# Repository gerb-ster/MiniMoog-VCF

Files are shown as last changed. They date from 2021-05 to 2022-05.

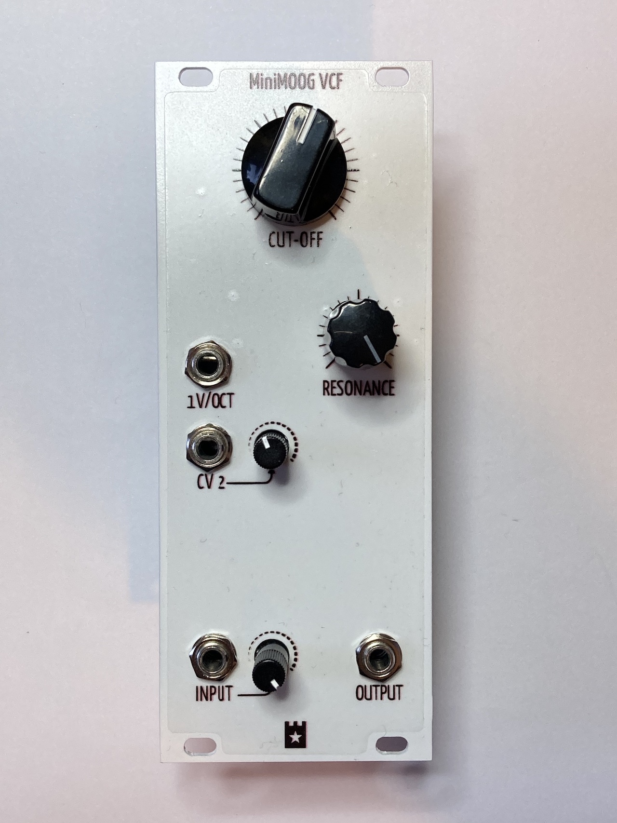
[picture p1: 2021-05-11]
images/IMG_3972.jpeg

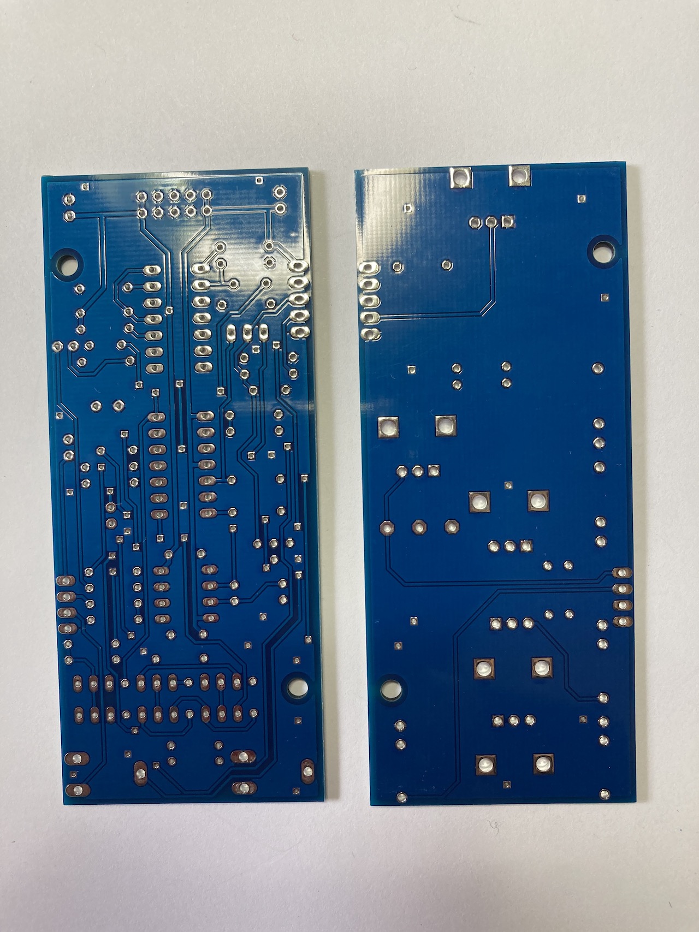
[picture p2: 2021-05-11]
images/IMG_3997.jpeg

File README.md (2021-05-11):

# YUSynth MiniMoog VCF

No system is complete without some good VCF’s. And one excellent source for some good VCF is designs is, offcourse, the website of Yven Usson, also known as YuSynth. And this VCF is no exception. It’s a clone of the famous VCF found in the MiniMoog. I’ve made an eurorack version.

## Status: Finished

- done: first schematic & board design
- done: breadboard and test
- done: design frontpanel
- done: order PCB and build prototype

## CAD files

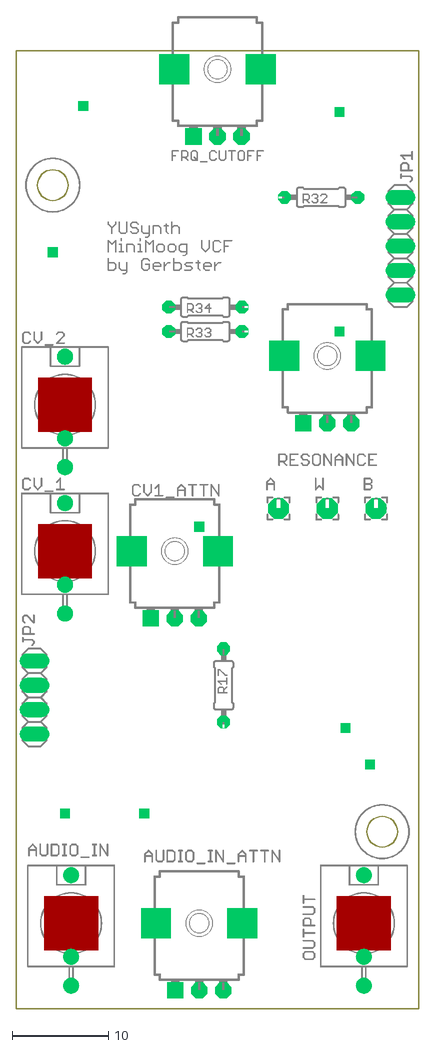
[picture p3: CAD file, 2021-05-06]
faceplates/MoogFilter.dxf
41.9 x 103.3

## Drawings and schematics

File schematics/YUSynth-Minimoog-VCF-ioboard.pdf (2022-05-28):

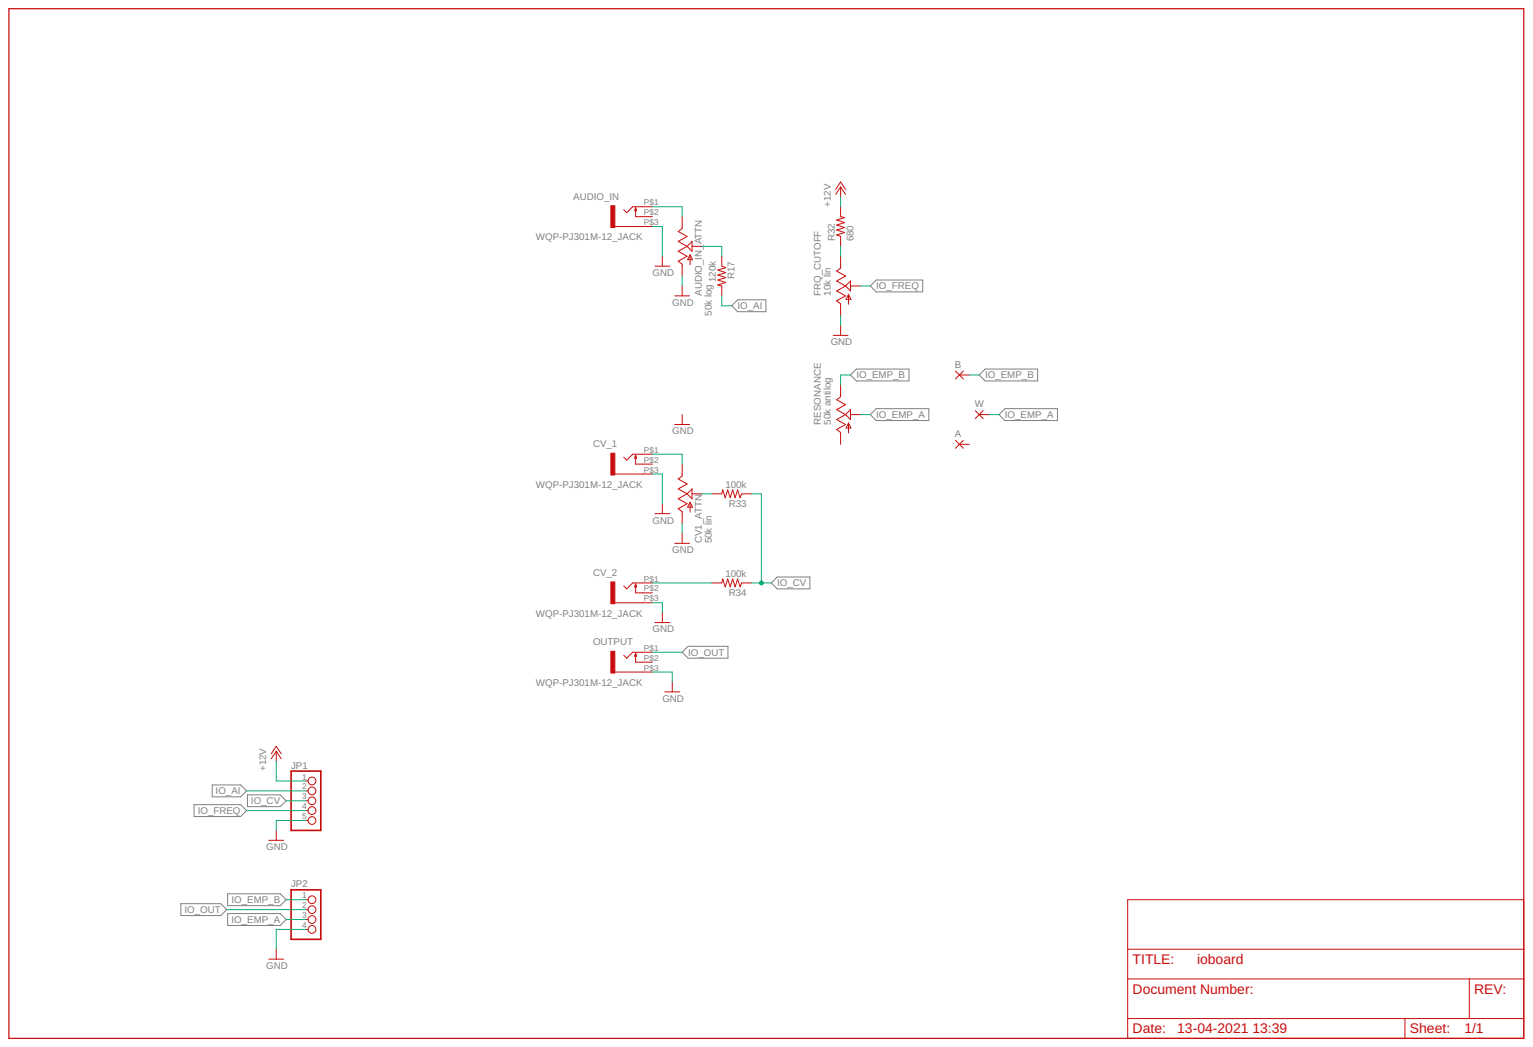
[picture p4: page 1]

120k GND GND +12V GND680 WQP-PJ301M-12_JACK WQP-PJ301M-12_JACK WQP-PJ301M-12_JACK WQP-PJ301M-12_JACK 10k lin 50k antilog 50k lin GND GND GNDGND +12V GND 50k log 100k 100k GND GND R17 12345 JP1 R32P$3 P$1 P$2 AUDIO_IN P$3 P$1 P$2 CV_1 P$3 P$1 P$2 CV_2 P$3 P$1 P$2 OUTPUT FRQ_CUTOFF RESONANCE CV1_ATTN AUDIO_IN_ATTN R33 R34 1234 JP2 B W A IO_AI IO_AI IO_CV IO_CV IO_OUT IO_OUT IO_EMP_B IO_EMP_B IO_EMP_B IO_EMP_A IO_EMP_A IO_EMP_A IO_FREQ IO_FREQ Date: Sheet: REV: TITLE: Document Number: 13-04-2021 13:39 1/1 ioboard

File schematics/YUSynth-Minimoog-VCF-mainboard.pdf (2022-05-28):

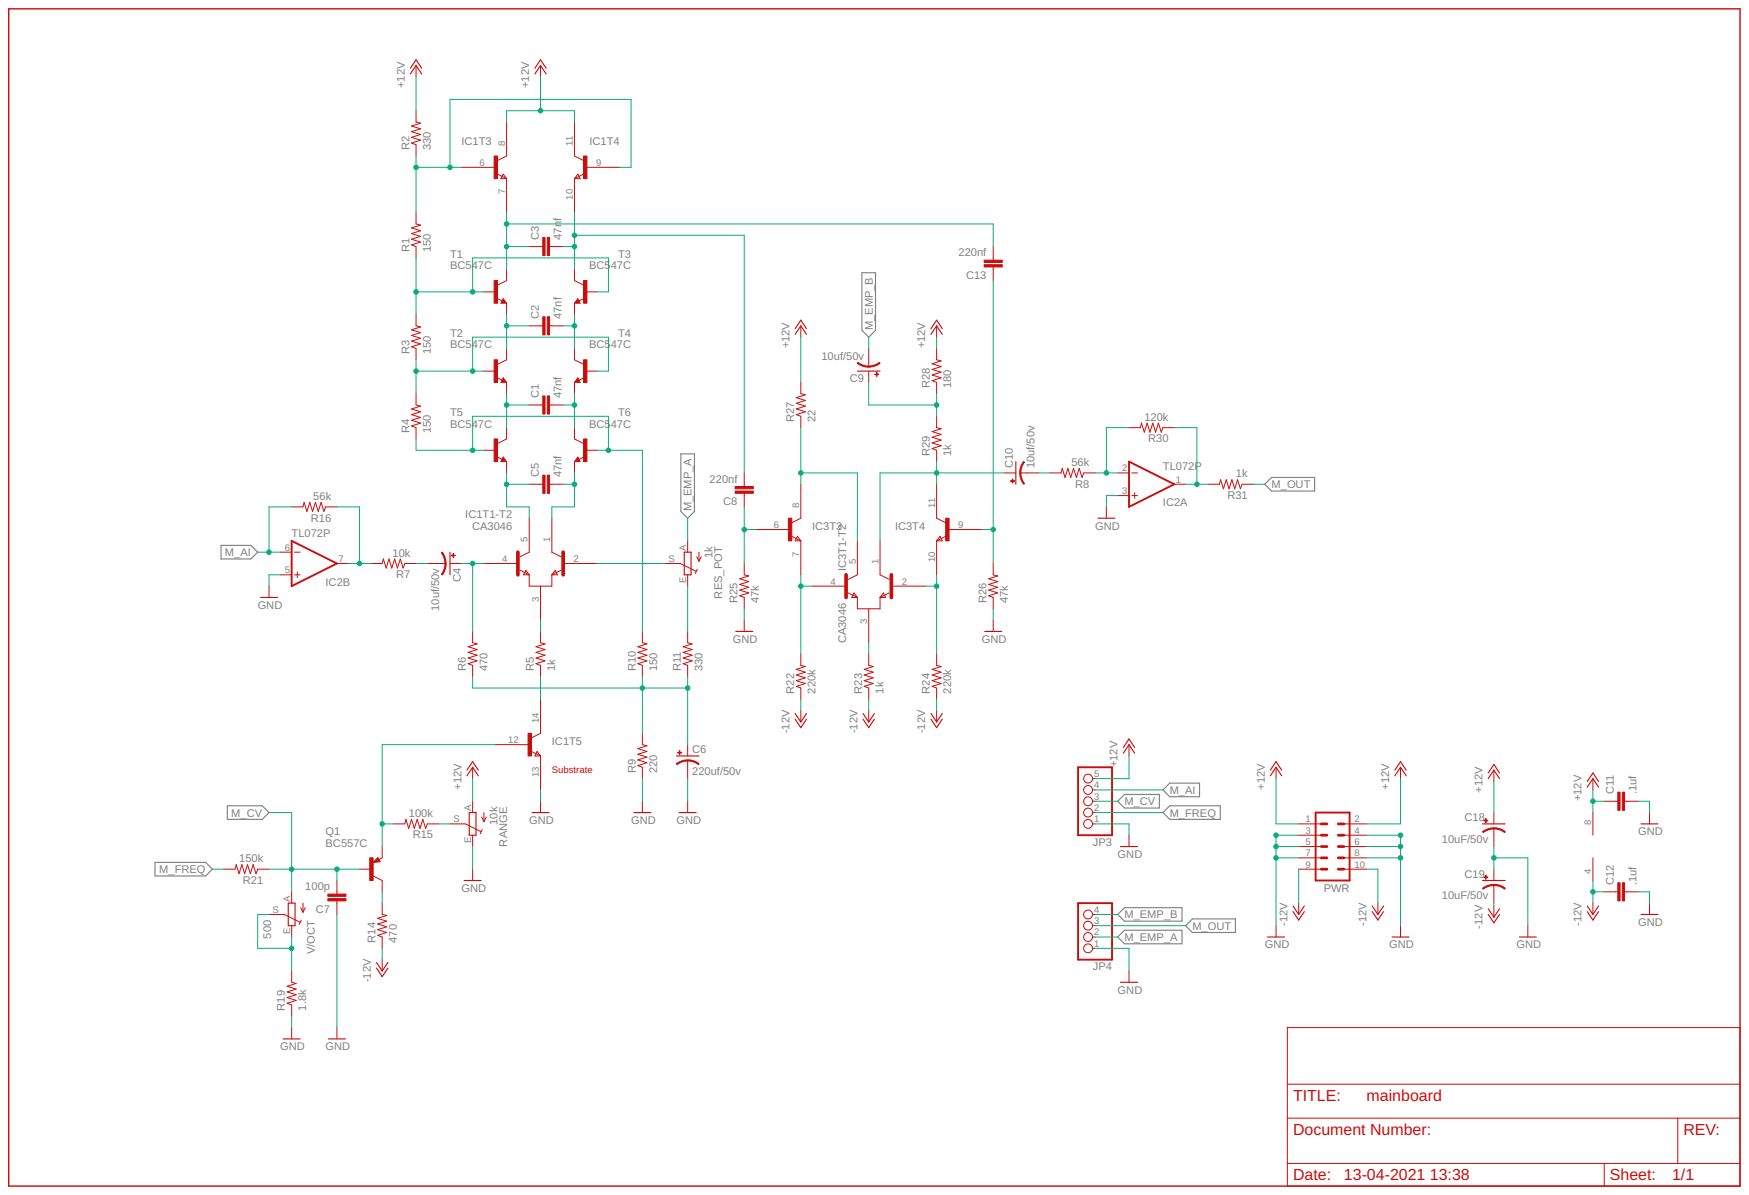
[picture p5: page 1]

Document Number: | REV:

Date: 13-04-2021 13:38 | Sheet: 1/1

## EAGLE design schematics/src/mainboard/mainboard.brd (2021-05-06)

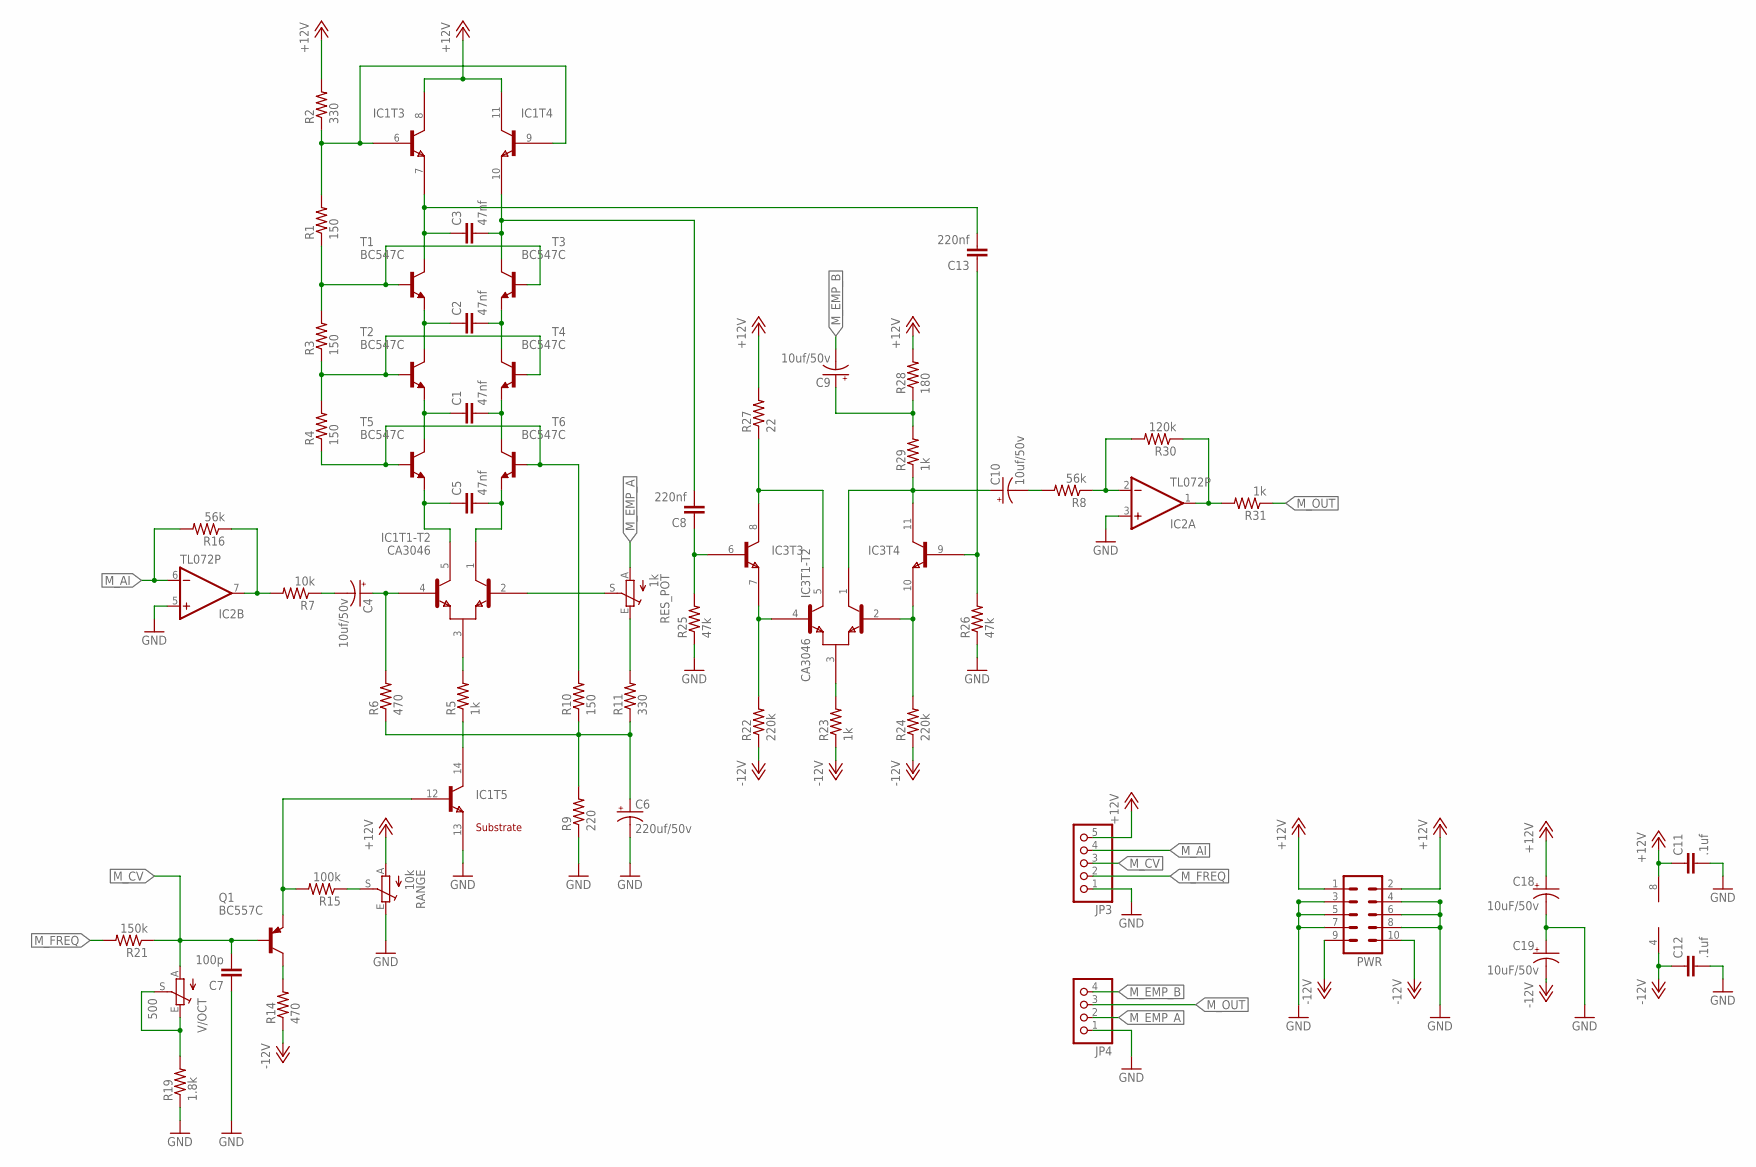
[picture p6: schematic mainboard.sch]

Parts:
C1, C2, C3, C5: 47nf; C050-024X044
C4, C9, C10: 10uf/50v; E2,5-5
C6: 220uf/50v; E3,5-10
C7: 100p; C050-024X044
C8, C13: 220nf; C050-024X044
C11, C12: .1uf; C050-024X044
C18, C19: 10uF/50v; E2,5-6
IC1, IC3: CA3046; DIL14
IC2: TL072P; DIL08
JP3: PINHD-1X5; 1X05
JP4: PINHD-1X4; 1X04
PWR: ML10
Q1: BC557C; TO92-EBC
R1, R3, R4, R10: 150; 0204/7
R2, R11: 330; 0204/7
R5, R23, R29, R31: 1k; 0204/7
R6, R14: 470; 0204/7
R7: 10k; 0204/7
R8, R16: 56k; 0204/7
R9: 220; 0204/7
R15: 100k; 0204/7
R19: 1.8k; 0204/7
R21: 150k; 0204/7
R22, R24: 220k; 0204/7
R25, R26: 47k; 0204/7
R27: 22; 0204/7
R28: 180; 0204/7
R30: 120k; 0204/7
RANGE: 10k; CA9V
RES_POT: 1k; CA9V
T1, T2, T3, T4, T5, T6: BC547C; TO92-CBE
V/OCT: 500; S64YW

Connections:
+12V: C11.1, C18.+, IC1.8 (C), IC1.11 (C), IC2.8 (V+), JP3.5, PWR.1, PWR.2, R2.2, R27.2, R28.2, RANGE.A
-12V: C12.1, C19.-, IC2.4 (V-), PWR.9, PWR.10, R14.1, R22.1, R23.1, R24.1
GND: C6.-, C7.1, C11.2, C12.2, C18.-, C19.+, IC1.13 (E), IC2.3 (+IN), IC2.5 (+IN), JP3.1, JP4.1, PWR.3, PWR.4, PWR.5, PWR.6, PWR.7, PWR.8, R9.1, R19.1, R25.1, R26.1, RANGE.E
M_AI: IC2.6 (-IN), JP3.4, R16.2
M_CV: C7.2, JP3.3, Q1.B, R21.1, V/OCT.A
M_EMP_A: JP4.2, RES_POT.A
M_EMP_B: C9.-, JP4.4
M_FREQ: JP3.2, R21.2
M_OUT: JP4.3, R31.1
unnamed: C5.1, IC1.5 (C2), T5.E
unnamed: IC1.6 (B), IC1.9 (B), R1.2, R2.1
unnamed: C3.1, C13.2, IC1.7 (E), T1.C
unnamed: C3.2, C8.2, IC1.10 (E), T3.C
unnamed: C2.1, T1.E, T2.C
unnamed: C2.2, T3.E, T4.C
unnamed: C1.1, T2.E, T5.C
unnamed: C1.2, T4.E, T6.C
unnamed: R1.1, R3.2, T1.B, T3.B
unnamed: R3.1, R4.2, T2.B, T4.B
unnamed: R4.1, R10.2, T5.B, T6.B
unnamed: C5.2, IC1.1 (C1), T6.E
unnamed: IC1.3 (E), R5.2
unnamed: IC1.14 (C), R5.1
unnamed: C4.+, IC1.4 (B2), R6.2
unnamed: C4.-, R7.1
unnamed: C6.+, R6.1, R9.2, R10.1, R11.1
unnamed: IC2.7 (OUT), R7.2, R16.1
unnamed: R19.2, V/OCT.E, V/OCT.S
unnamed: IC1.12 (B), Q1.E, R15.2
unnamed: IC1.2 (B1), RES_POT.S
unnamed: R11.2, RES_POT.E
unnamed: C13.1, IC3.9 (B), R26.2
unnamed: Q1.C, R14.2
unnamed: R15.1, RANGE.S
unnamed: C10.-, R8.2
unnamed: IC3.4 (B2), IC3.7 (E), R22.2
unnamed: IC3.3 (E), R23.2
unnamed: IC3.2 (B1), IC3.10 (E), R24.2
unnamed: IC3.5 (C2), IC3.8 (C), R27.1
unnamed: C10.+, IC3.1 (C1), IC3.11 (C), R29.1
unnamed: C9.+, R28.1, R29.2
unnamed: IC2.1 (OUT), R30.1, R31.2
unnamed: C8.1, IC3.6 (B), R25.2
unnamed: IC2.2 (-IN), R8.1, R30.2

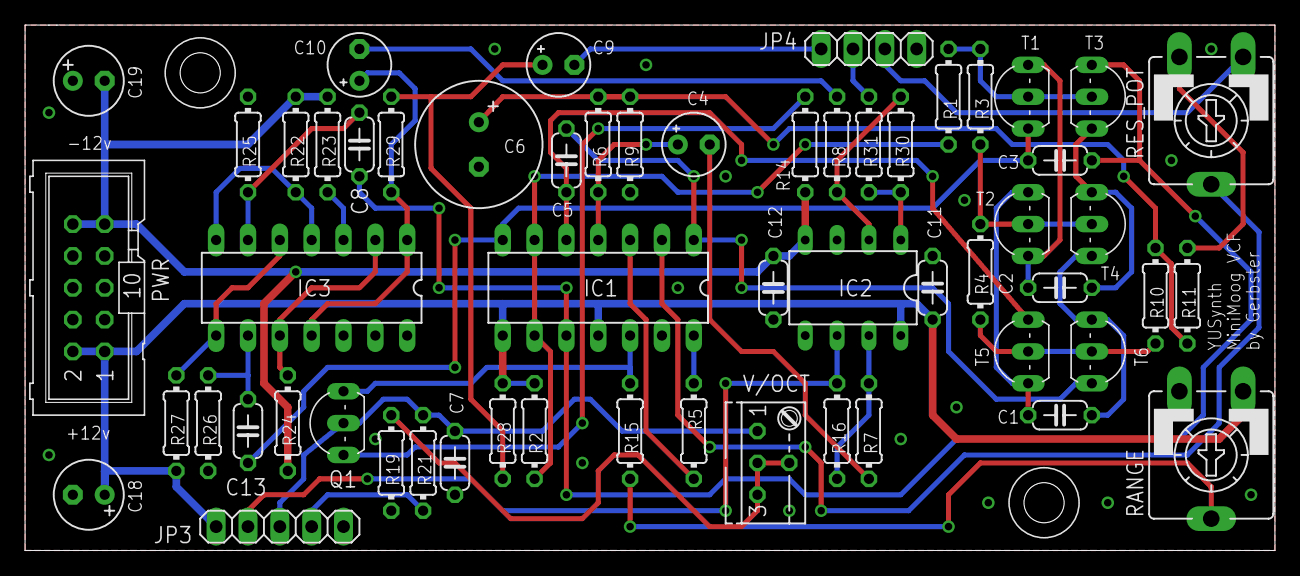
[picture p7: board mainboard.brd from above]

Board: 2 copper layers, 99.7 x 41.9 mm, 57 parts (0 on the bottom side), 44 nets.

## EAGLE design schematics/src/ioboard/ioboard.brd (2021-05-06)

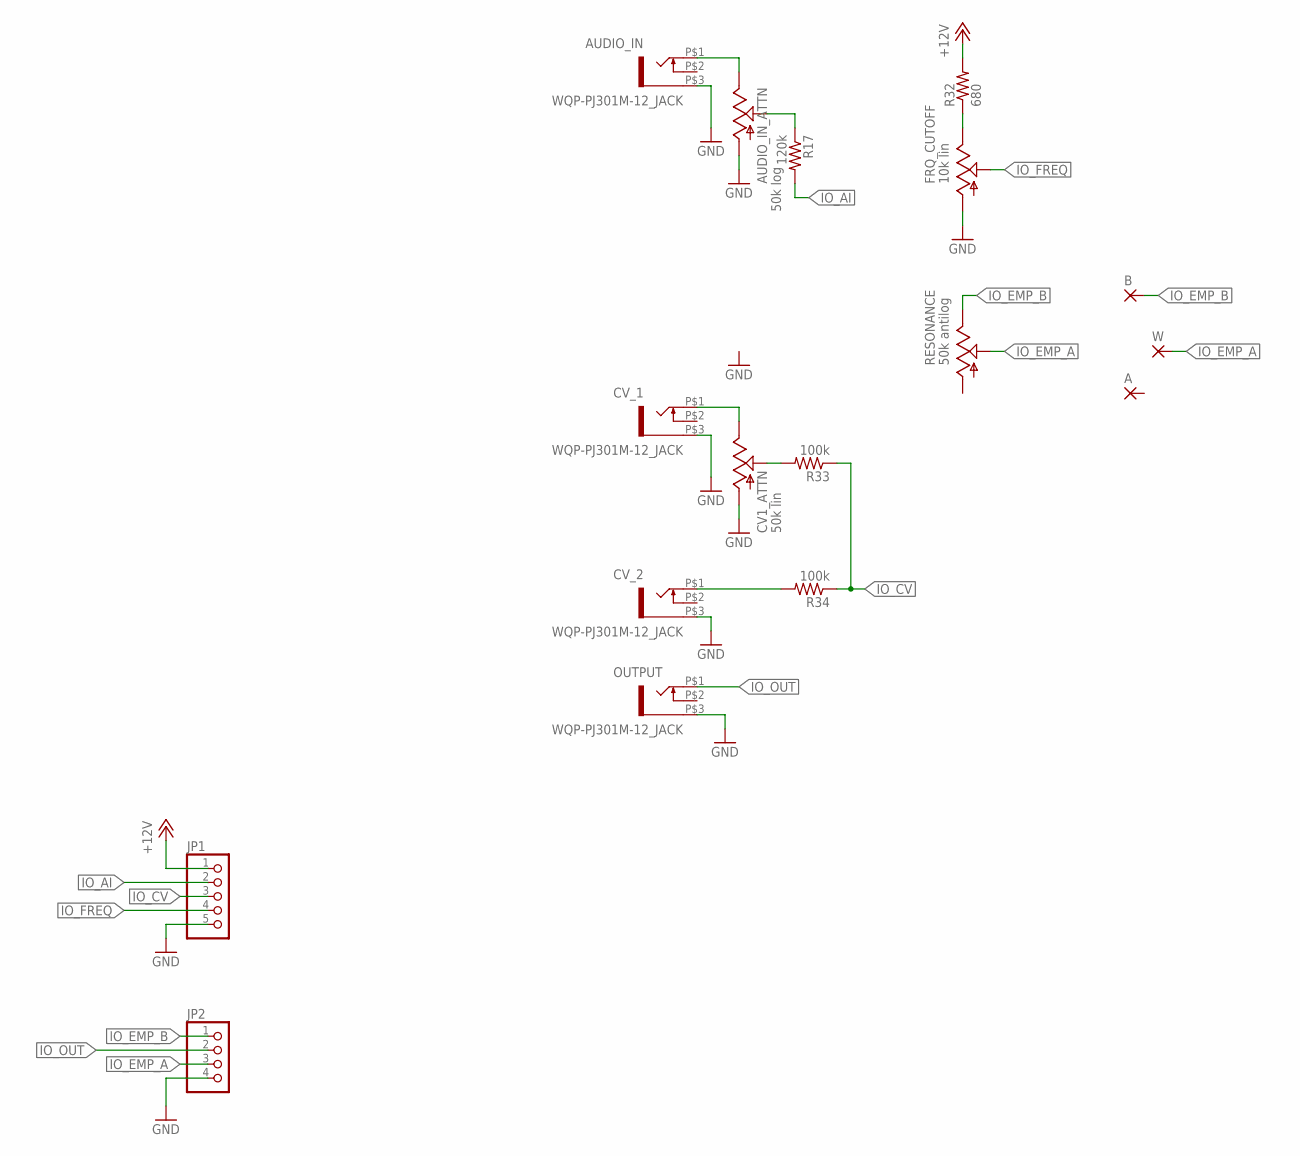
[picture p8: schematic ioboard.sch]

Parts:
A: 2,15/1,0
AUDIO_IN: WQP-PJ301M-12_JACK
AUDIO_IN_ATTN: 50k log; EVUF
B: 2,15/1,0
CV1_ATTN: 50k lin; EVUF
CV_1, CV_2: WQP-PJ301M-12_JACK
FRQ_CUTOFF: 10k lin; EVUF
JP1: PINHD-1X5; 1X05
JP2: PINHD-1X4; 1X04
OUTPUT: WQP-PJ301M-12_JACK
R17: 120k; 0204/7
R32: 680; 0204/7
R33, R34: 100k; 0204/7
RESONANCE: 50k antilog; EVUF
W: 2,15/1,0

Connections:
+12V: JP1.1, R32.2
GND: AUDIO_IN.P$3 (1), AUDIO_IN_ATTN.1 (A), CV1_ATTN.1 (A), CV_1.P$3 (1), CV_2.P$3 (1), FRQ_CUTOFF.1 (A), JP1.5, JP2.4, OUTPUT.P$3 (1)
IO_AI: JP1.2, R17.2
IO_AI_1: AUDIO_IN_ATTN.2 (S), R17.1
IO_CV: JP1.3, R33.1, R34.1
IO_EMP_A: JP2.3, RESONANCE.2 (S), W.1
IO_EMP_B: B.1, JP2.1, RESONANCE.3 (E)
IO_FREQ: FRQ_CUTOFF.2 (S), JP1.4
IO_OUT: JP2.2, OUTPUT.P$1 (2)
unnamed: FRQ_CUTOFF.3 (E), R32.1
unnamed: CV1_ATTN.3 (E), CV_1.P$1 (2)
unnamed: CV1_ATTN.2 (S), R33.2
unnamed: CV_2.P$1 (2), R34.2
unnamed: AUDIO_IN.P$1 (2), AUDIO_IN_ATTN.3 (E)

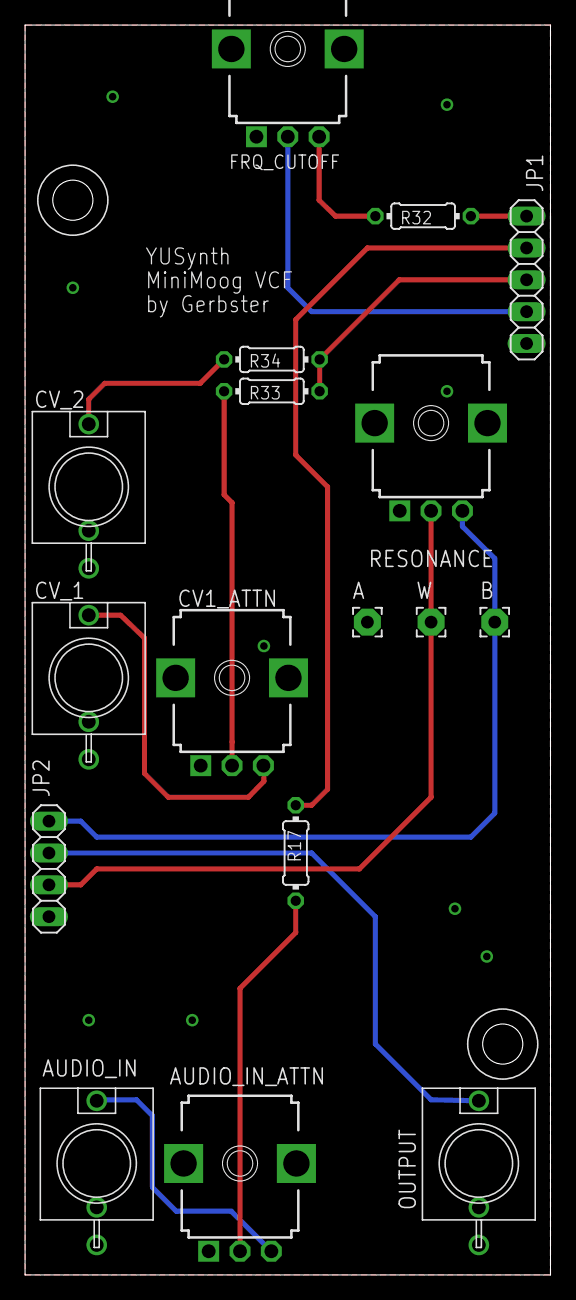
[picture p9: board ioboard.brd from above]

Board: 2 copper layers, 41.9 x 99.7 mm, 17 parts (0 on the bottom side), 14 nets.

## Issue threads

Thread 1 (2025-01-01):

Board outline problem with JLCPCB

Sebastsch, 2025-01-01:
Hi, I would like to redo your module however JLCPCB reports an error on the ioboard PCB. Here is their message: "1.Hi Sir/Madam, there is no board outline in your file, please kindly check it!You can click ‘Replace file’ button to re-upload the file in your JLCPCB account page .Thanks" . Indeed the profile.gbr file seems corrupted, can you confirm this? Thank you very much for your help and your work.

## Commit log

2021-05-06 some files
    [MoogFilter.brd, MoogFilter.dxf, MoogFilter.sch]
2021-05-07 Added files & structure
    [YUSynth-Minimoog-VCF-ioboard.GBL, YUSynth-Minimoog-VCF-ioboard.GBO, YUSynth-Minimoog-VCF-ioboard.GBP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]
2021-08-06 Updated some schematics and docs
    [YUSynth-Minimoog-VCF-ioboard.GBL, YUSynth-Minimoog-VCF-ioboard.GBO, YUSynth-Minimoog-VCF-ioboard.GBP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]
2021-08-10 Fixed some bugs and updated documentation
    [YUSynth-Minimoog-VCF-ioboard.XLN, YUSynth-Minimoog-VCF-mainboard.XLN, gerber_job.gbrjob]
2022-04-20 Some updates & bugfixes
    [YUSynth-Minimoog-VCF-ioboard.XLN, YUSynth-Minimoog-VCF-mainboard.XLN, gerber_job.gbrjob]
2022-04-22 Fixed schematics & descriptions
    [YUSynth-Minimoog-VCF-ioboard.XLN, YUSynth-Minimoog-VCF-mainboard.XLN, gerber_job.gbrjob]
2022-05-17 Updated Firmware
    [YUSynth-Minimoog-VCF-ioboard.XLN, YUSynth-Minimoog-VCF-mainboard.XLN, gerber_job.gbrjob]
2022-05-18 Updated Faceplates
    [YUSynth-Minimoog-VCF-ioboard.XLN, YUSynth-Minimoog-VCF-mainboard.XLN, gerber_job.gbrjob]
2022-05-18 Fixed issues
    [YUSynth-Minimoog-VCF-ioboard.XLN, YUSynth-Minimoog-VCF-mainboard.XLN, gerber_job.gbrjob]
2022-05-21 Fixed schematics
    [YUSynth-Minimoog-VCF-ioboard.XLN, YUSynth-Minimoog-VCF-mainboard.XLN, gerber_job.gbrjob]
2022-05-28 General updates
    [YUSynth-Minimoog-VCF-ioboard.GKO, YUSynth-Minimoog-VCF-mainboard.GKO, copper_bottom.gbr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]
